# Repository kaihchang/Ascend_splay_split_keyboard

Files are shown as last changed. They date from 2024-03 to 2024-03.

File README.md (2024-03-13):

# Kai Ascend, a wireless split keyboard with encoders & displays

First time designing my own keyboard. Also my first Kicad project.

I wanted a board with both MX and Choc switches, creating a natural elevation when used without wrist rests. One of the reasons I start using split ergos is to save desk space, so I'd like my board to be wireless (utilizing ZMK) and not rely on extra supports like wrist rests.
Thought about getting rid of "Q" and "P" positions since I prefer using extra pinky column (same as pinky column in schema but anyway) for those, but then that doesn't really save any space and pin, so I kept them eventually.

Honestly not super satisfied with the splays and extra pinky columns. Maybe I can make the whole thing a bit smaller with spreads.

PCB:

Build:

With tenting:


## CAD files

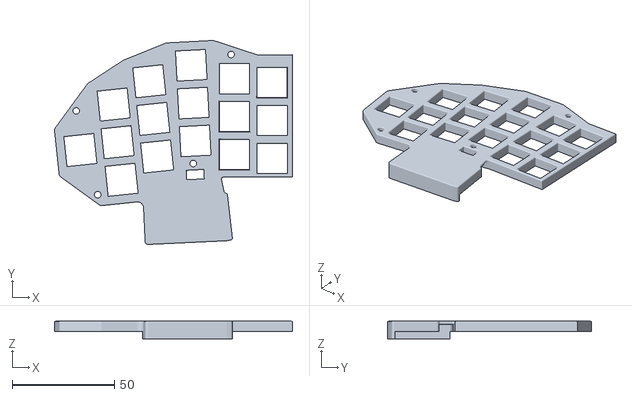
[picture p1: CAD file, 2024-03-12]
stl/shell_MX_left.stl
116.2 x 99.6 x 8.55

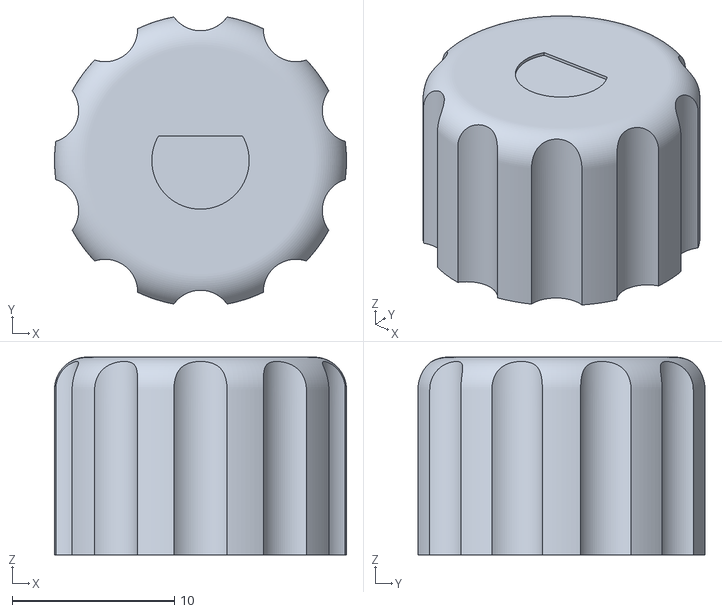
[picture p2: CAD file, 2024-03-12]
stl/EC11_12mm_knob.stl
18.0 x 17.7 x 12.2

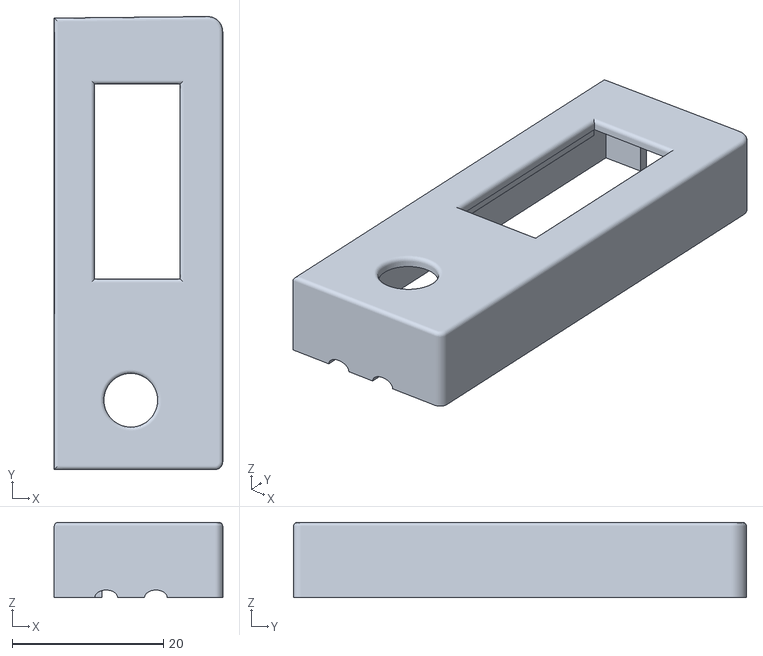
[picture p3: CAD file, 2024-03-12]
stl/MCU_cover_left.stl
22.3 x 60.0 x 9.96

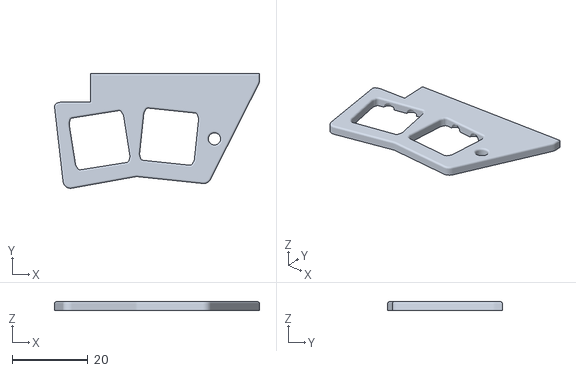
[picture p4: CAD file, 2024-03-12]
stl/shell_Choc_left.stl
54.0 x 30.2 x 2.30

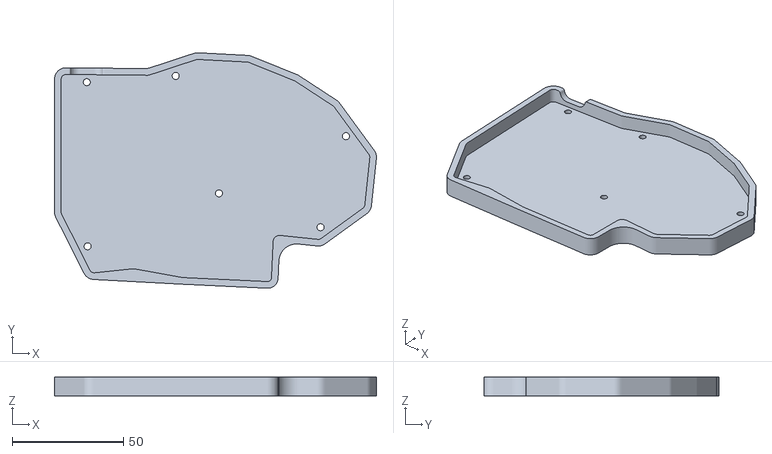
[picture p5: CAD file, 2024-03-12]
stl/ascend_case_right.stl
144.9 x 105.9 x 8.40

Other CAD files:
stl/shell_MX_right.stl
stl/MCU_cover_right.stl
stl/shell_Choc_right.stl
stl/ascend_case_left.stl

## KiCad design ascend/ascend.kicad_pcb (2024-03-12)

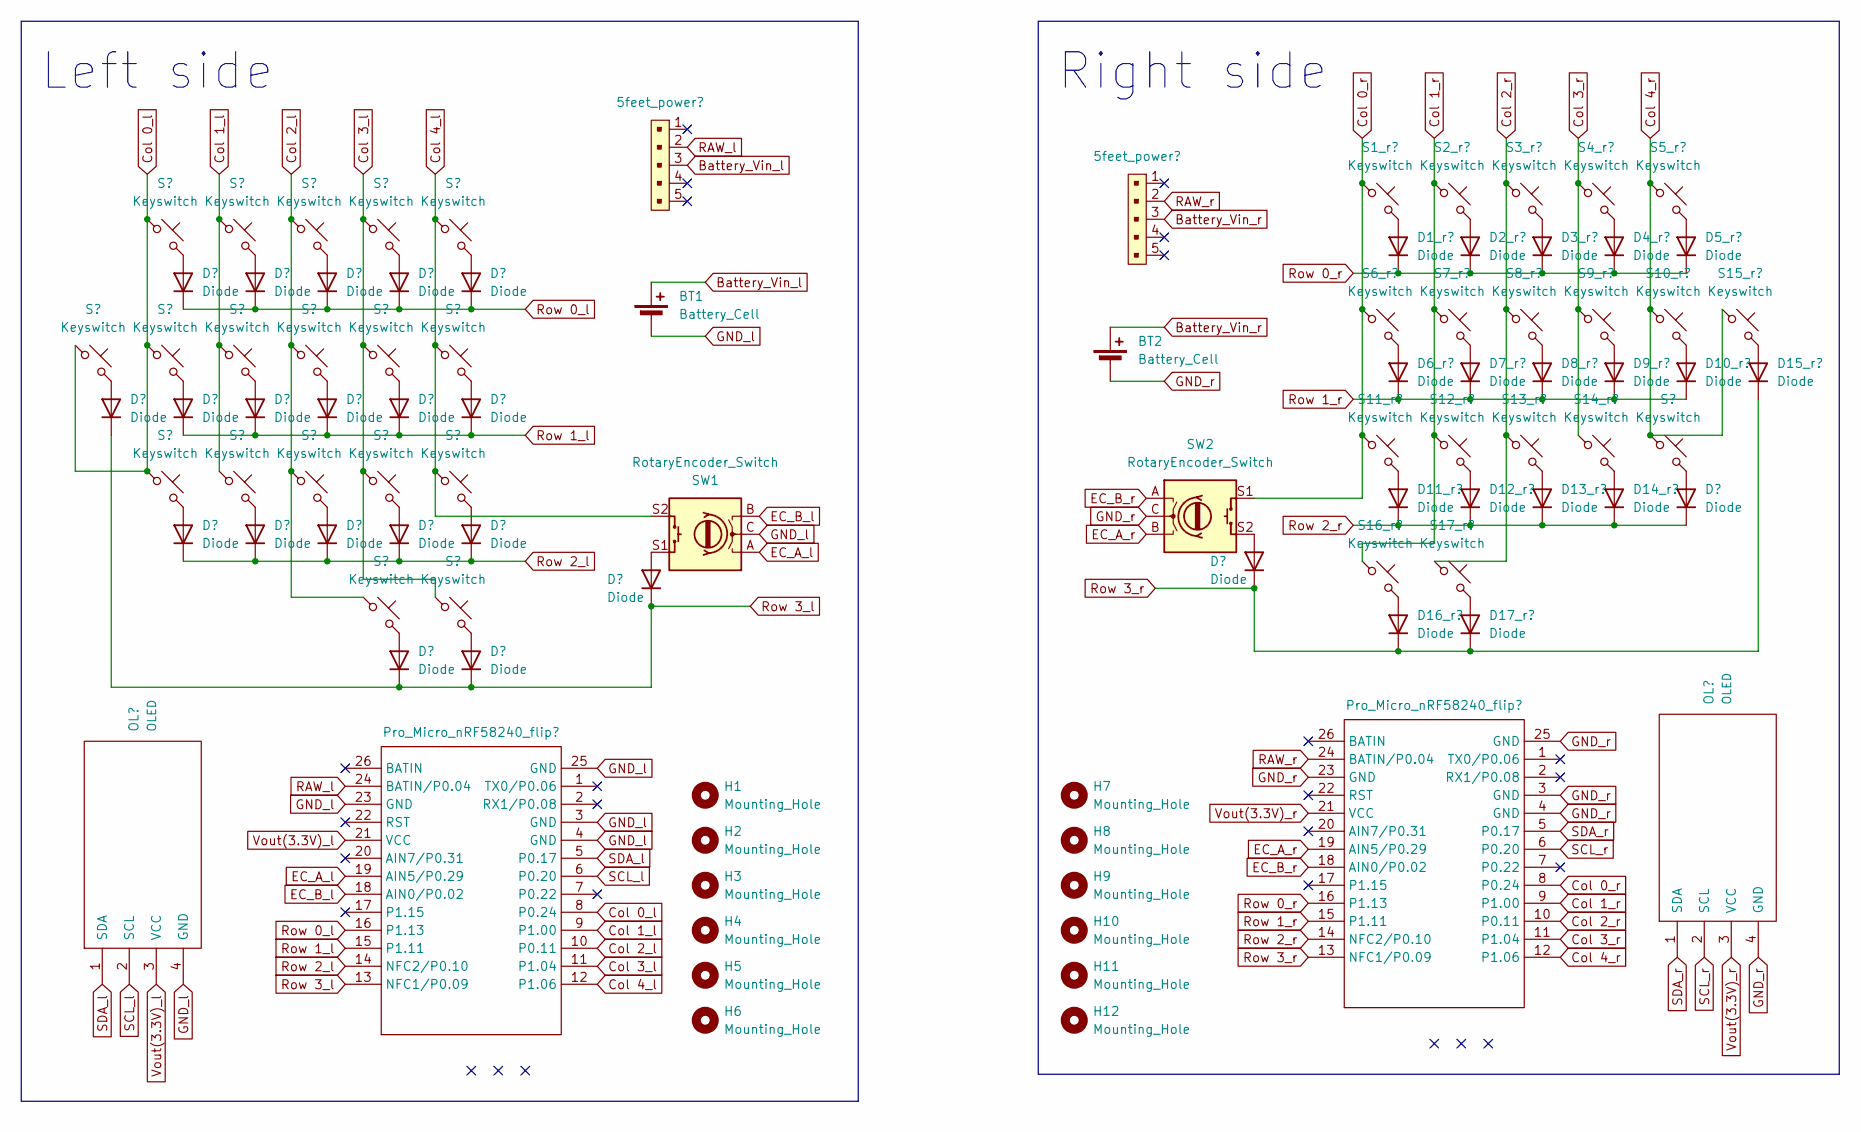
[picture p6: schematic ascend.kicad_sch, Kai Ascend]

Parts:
5feet_power1, 5feet_power2: B5B-XH-A_LF__SN_; Switch_slide_TH_5P; MPN B5B-XH-A(LF)(SN); Digi-Key_PN 455-2270-ND
BT1, BT2: Battery_Cell; JST_XH_2.54mm_vertical
D1, D1_r1, D2, D2_r1, D3, D3_r1, D4, D4_r1, D5, D5_r1, D6, D6_r1, D7, D7_r1, D8, D8_r1, D9, D9_r1, D10, D10_r1, D11, D11_r1, D12, D12_r1, D13, D13_r1, D14, D14_r1, D15, D15_r1, D16, D16_r1, D17, D17_r1, D18, D18_r1, D19, D20: Diode; Compatible_diode_TH_SMD
H1, H2, H3, H4, H5, H6, H7, H8, H9, H10, H11, H12: Mounting_Hole; MountingHole_3.2mm_M3
OL1, OL2: OLED; OLED_v2
Pro_Micro_nRF58240_flip1, Pro_Micro_nRF58240_flip2: Pro Micro nRF52840
S1, S1_r1, S2, S2_r1, S3, S3_r1, S4, S5, S5_r1, S6, S6_r1, S7, S7_r1, S8, S9, S9_r1, S10, S10_r1, S11, S11_r1, S12, S12_r1, S13, S13_r1, S14_r1, S15, S15_r1, S16, S16_r1, S17, S17_r1, S18_r1: Keyswitch; Hotswap_MX_Plated_1.00u
S4_r1, S8_r1, S14, S18: Keyswitch; Hotswap_Choc_V1_Plated_1.00u
SW1, SW2: RotaryEncoder_Switch; RotaryEncoder_Alps_EC12E-Switch_Vertical_H20mm

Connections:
Battery_Vin_l: 5feet_power1.3, BT1.1 (+)
Battery_Vin_r: 5feet_power2.3, BT2.1 (+)
Col 0_l: Pro_Micro_nRF58240_flip1.8 (P0.24), S1.1, S2.1, S3.1, S4.1
Col 0_r: Pro_Micro_nRF58240_flip2.8 (P0.24), S1_r1.1, S2_r1.1, S3_r1.1, SW2.S1
Col 1_l: Pro_Micro_nRF58240_flip1.9 (P1.00), S5.1, S6.1, S7.1
Col 1_r: Pro_Micro_nRF58240_flip2.9 (P1.00), S4_r1.1, S5_r1.1, S6_r1.1, S7_r1.1
Col 2_l: Pro_Micro_nRF58240_flip1.10 (P0.11), S8.1, S9.1, S10.1, S14.1
Col 2_r: Pro_Micro_nRF58240_flip2.10 (P0.11), S8_r1.1, S9_r1.1, S10_r1.1, S11_r1.1
Col 3_l: Pro_Micro_nRF58240_flip1.11 (P1.04), S11.1, S12.1, S13.1, S18.1
Col 3_r: Pro_Micro_nRF58240_flip2.11 (P1.04), S12_r1.1, S13_r1.1, S14_r1.1
Col 4_l: Pro_Micro_nRF58240_flip1.12 (P1.06), S15.1, S16.1, S17.1, SW1.S2
Col 4_r: Pro_Micro_nRF58240_flip2.12 (P1.06), S15_r1.1, S16_r1.1, S17_r1.1, S18_r1.1
EC_A_l: Pro_Micro_nRF58240_flip1.19 (AIN5/P0.29), SW1.A
EC_A_r: Pro_Micro_nRF58240_flip2.19 (AIN5/P0.29), SW2.B
EC_B_l: Pro_Micro_nRF58240_flip1.18 (AIN0/P0.02), SW1.B
EC_B_r: Pro_Micro_nRF58240_flip2.18 (AIN0/P0.02), SW2.A
GND_l: BT1.2 (-), OL1.4 (GND), Pro_Micro_nRF58240_flip1.3 (GND), Pro_Micro_nRF58240_flip1.4 (GND), Pro_Micro_nRF58240_flip1.23 (GND), Pro_Micro_nRF58240_flip1.25 (GND), SW1.C
GND_r: BT2.2 (-), OL2.4 (GND), Pro_Micro_nRF58240_flip2.3 (GND), Pro_Micro_nRF58240_flip2.4 (GND), Pro_Micro_nRF58240_flip2.23 (GND), Pro_Micro_nRF58240_flip2.25 (GND), SW2.C
unnamed: D1.2 (A), S1.2
unnamed: D1_r1.2 (A), S1_r1.2
unnamed: D2.2 (A), S2.2
unnamed: D2_r1.2 (A), S2_r1.2
unnamed: D3.2 (A), S3.2
unnamed: D3_r1.2 (A), S3_r1.2
unnamed: D4.2 (A), S4.2
unnamed: D4_r1.2 (A), S4_r1.2
unnamed: D5.2 (A), S5.2
unnamed: D5_r1.2 (A), S5_r1.2
unnamed: D6.2 (A), S6.2
unnamed: D6_r1.2 (A), S6_r1.2
unnamed: D7.2 (A), S7.2
unnamed: D7_r1.2 (A), S7_r1.2
unnamed: D8.2 (A), S8.2
unnamed: D8_r1.2 (A), S8_r1.2
unnamed: D9.2 (A), S9.2
unnamed: D9_r1.2 (A), S9_r1.2
unnamed: D10.2 (A), S10.2
unnamed: D10_r1.2 (A), S10_r1.2
unnamed: D11.2 (A), S11.2
unnamed: D11_r1.2 (A), S11_r1.2
unnamed: D12.2 (A), S12.2
unnamed: D12_r1.2 (A), S12_r1.2
unnamed: D13.2 (A), S13.2
unnamed: D13_r1.2 (A), S13_r1.2
unnamed: D14.2 (A), S14.2
unnamed: D14_r1.2 (A), S14_r1.2
unnamed: D15.2 (A), S15.2
unnamed: D15_r1.2 (A), S15_r1.2
unnamed: D16.2 (A), S16.2
unnamed: D16_r1.2 (A), S16_r1.2
unnamed: D17.2 (A), S17.2
unnamed: D17_r1.2 (A), S17_r1.2
unnamed: D18.2 (A), S18.2
unnamed: D18_r1.2 (A), S18_r1.2
unnamed: D19.2 (A), SW1.S1
unnamed: D20.2 (A), SW2.S2
RAW_l: 5feet_power1.2, Pro_Micro_nRF58240_flip1.24 (BATIN/P0.04)
RAW_r: 5feet_power2.2, Pro_Micro_nRF58240_flip2.24 (BATIN/P0.04)
Row 0_l: D2.1 (K), D5.1 (K), D8.1 (K), D11.1 (K), D15.1 (K), Pro_Micro_nRF58240_flip1.16 (P1.13)
Row 0_r: D1_r1.1 (K), D5_r1.1 (K), D9_r1.1 (K), D12_r1.1 (K), D15_r1.1 (K), Pro_Micro_nRF58240_flip2.16 (P1.13)
Row 1_l: D3.1 (K), D6.1 (K), D9.1 (K), D12.1 (K), D16.1 (K), Pro_Micro_nRF58240_flip1.15 (P1.11)
Row 1_r: D2_r1.1 (K), D6_r1.1 (K), D10_r1.1 (K), D13_r1.1 (K), D16_r1.1 (K), Pro_Micro_nRF58240_flip2.15 (P1.11)
Row 2_l: D4.1 (K), D7.1 (K), D10.1 (K), D13.1 (K), D17.1 (K), Pro_Micro_nRF58240_flip1.14 (NFC2/P0.10)
Row 2_r: D3_r1.1 (K), D7_r1.1 (K), D11_r1.1 (K), D14_r1.1 (K), D17_r1.1 (K), Pro_Micro_nRF58240_flip2.14 (NFC2/P0.10)
Row 3_l: D1.1 (K), D14.1 (K), D18.1 (K), D19.1 (K), Pro_Micro_nRF58240_flip1.13 (NFC1/P0.09)
Row 3_r: D4_r1.1 (K), D8_r1.1 (K), D18_r1.1 (K), D20.1 (K), Pro_Micro_nRF58240_flip2.13 (NFC1/P0.09)
SCL_l: OL1.2 (SCL), Pro_Micro_nRF58240_flip1.6 (P0.20)
SCL_r: OL2.2 (SCL), Pro_Micro_nRF58240_flip2.6 (P0.20)
SDA_l: OL1.1 (SDA), Pro_Micro_nRF58240_flip1.5 (P0.17)
SDA_r: OL2.1 (SDA), Pro_Micro_nRF58240_flip2.5 (P0.17)
Vout(3.3V)_l: OL1.3 (VCC), Pro_Micro_nRF58240_flip1.21 (VCC)
Vout(3.3V)_r: OL2.3 (VCC), Pro_Micro_nRF58240_flip2.21 (VCC)

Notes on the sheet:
Left side
Right side

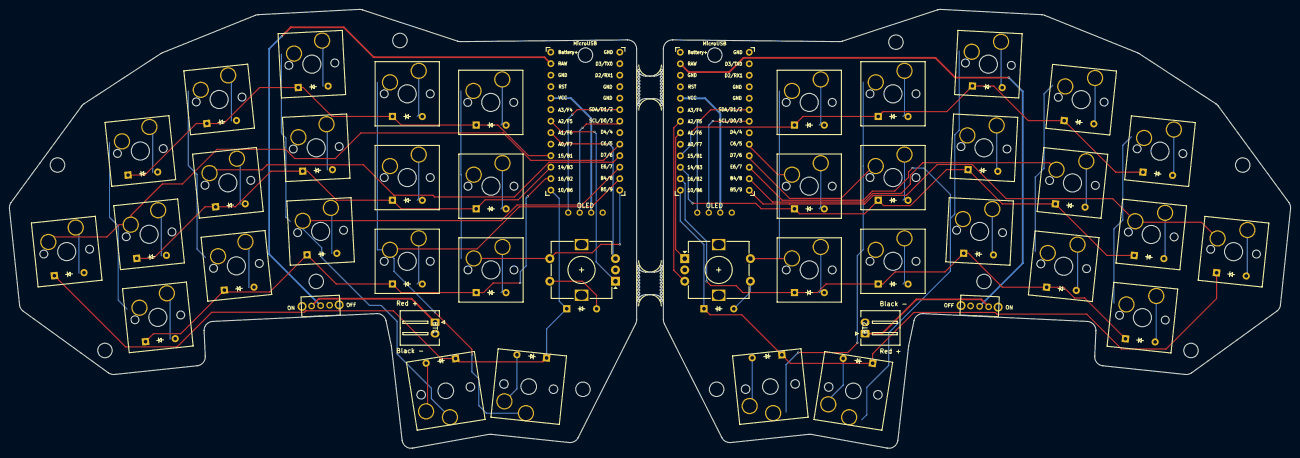
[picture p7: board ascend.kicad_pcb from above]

Board: 2 copper layers, 283.0 x 96.9 mm, 98 parts (0 on the bottom side), 72 nets.

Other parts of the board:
mouse-bite-5mm-slot, mouse-bite-5mm-slot#2: VAL**; mouse-bite-5mm-slot
